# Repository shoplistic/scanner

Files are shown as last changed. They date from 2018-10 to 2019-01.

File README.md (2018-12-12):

# Barcode Scanner

### Links
[Headless Setup](https://desertbot.io/blog/headless-pi-zero-w-wifi-setup-windows)  
[Original Source](https://www.pyimagesearch.com/2018/05/21/an-opencv-barcode-and-qr-code-scanner-with-zbar/)

### TODO:
* [x] Install script
* [ ] Diagram / Schematic
* [x] pwm?

### RPi Pinout
|  pin  |  bcm  | usecase |
| :---: | :---: | :--- |
|  11 |  17 | RED LED |
|  12 |  18 | LIGHTNING PWM |
|  13 |  27 | GREEN LED |
|  15 |  22 | BLUE LED |
|  16 |  23 | SENSOR |

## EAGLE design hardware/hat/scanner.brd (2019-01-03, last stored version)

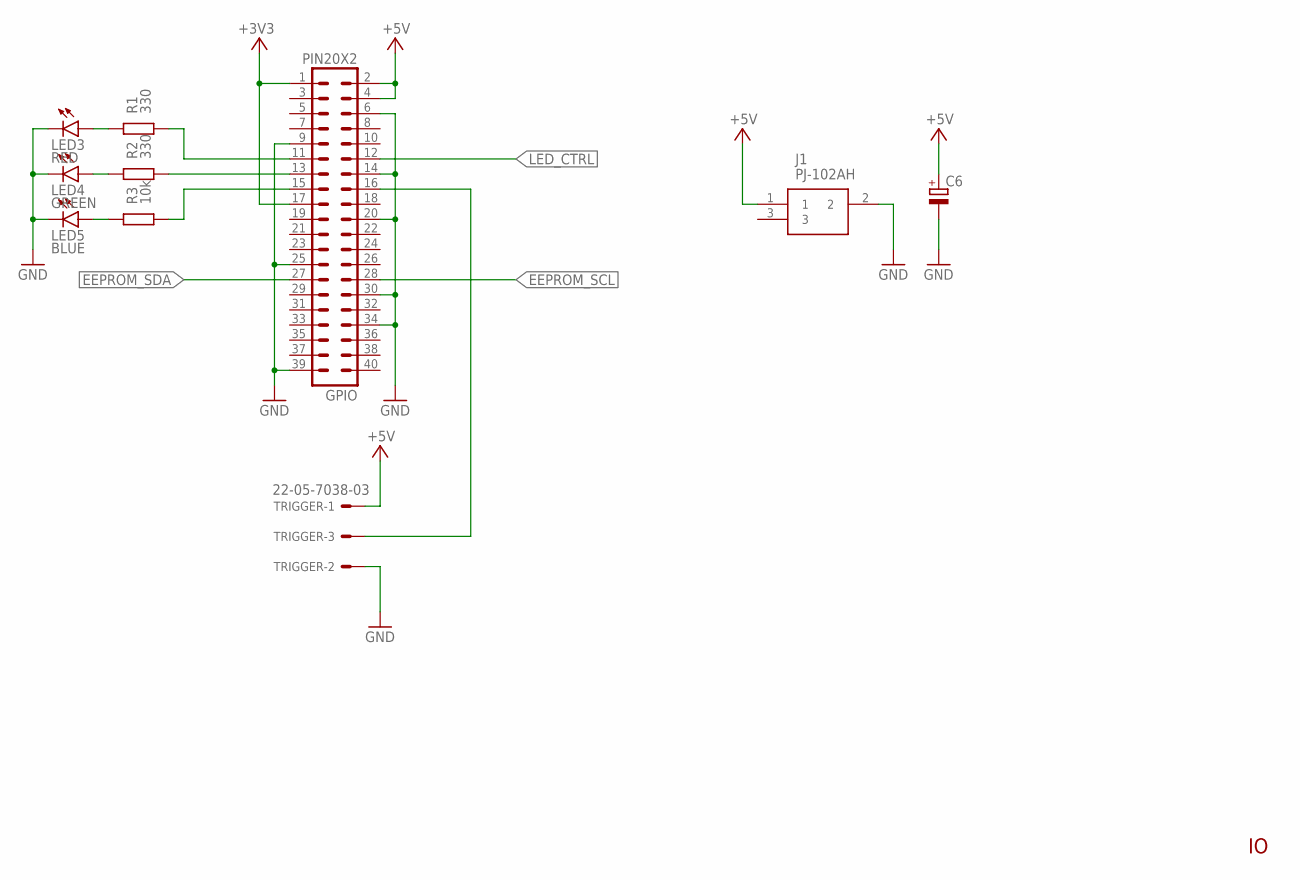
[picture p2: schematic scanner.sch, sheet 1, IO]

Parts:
C6: CPOL-EUCT6032; CT6032
GPIO: PIN20X2; PIN_20X2
J1: PJ-102AH
LED3: RED; CHIP-LED0805
LED4: GREEN; CHIP-LED0805
LED5: BLUE; CHIP-LED0805
R1, R2: 330; M0805; TOLERANCE 5%
R3: 10k; M0805; TOLERANCE 5%
TRIGGER: 22-05-7038-03; 7395-03

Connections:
+3V3: GPIO.1, GPIO.17; also elsewhere on the board
+5V: C6.+, GPIO.2, GPIO.4, J1.1, TRIGGER.1; also elsewhere on the board
EEPROM_SCL: GPIO.28; also elsewhere on the board
EEPROM_SDA: GPIO.27; also elsewhere on the board
GND: C6.-, GPIO.6, GPIO.9, GPIO.14, GPIO.20, GPIO.25, GPIO.30, GPIO.34, GPIO.39, J1.2, LED3.C, LED4.C, LED5.C, TRIGGER.2; also elsewhere on the board
LED3: GPIO.11, R1.1
LED4: GPIO.13, R2.1
LED5: GPIO.15, R3.1
LED_CTRL: GPIO.12; also elsewhere on the board
unnamed: LED3.A, R1.2
unnamed: LED4.A, R2.2
unnamed: LED5.A, R3.2
TRIGGER: GPIO.16, TRIGGER.3

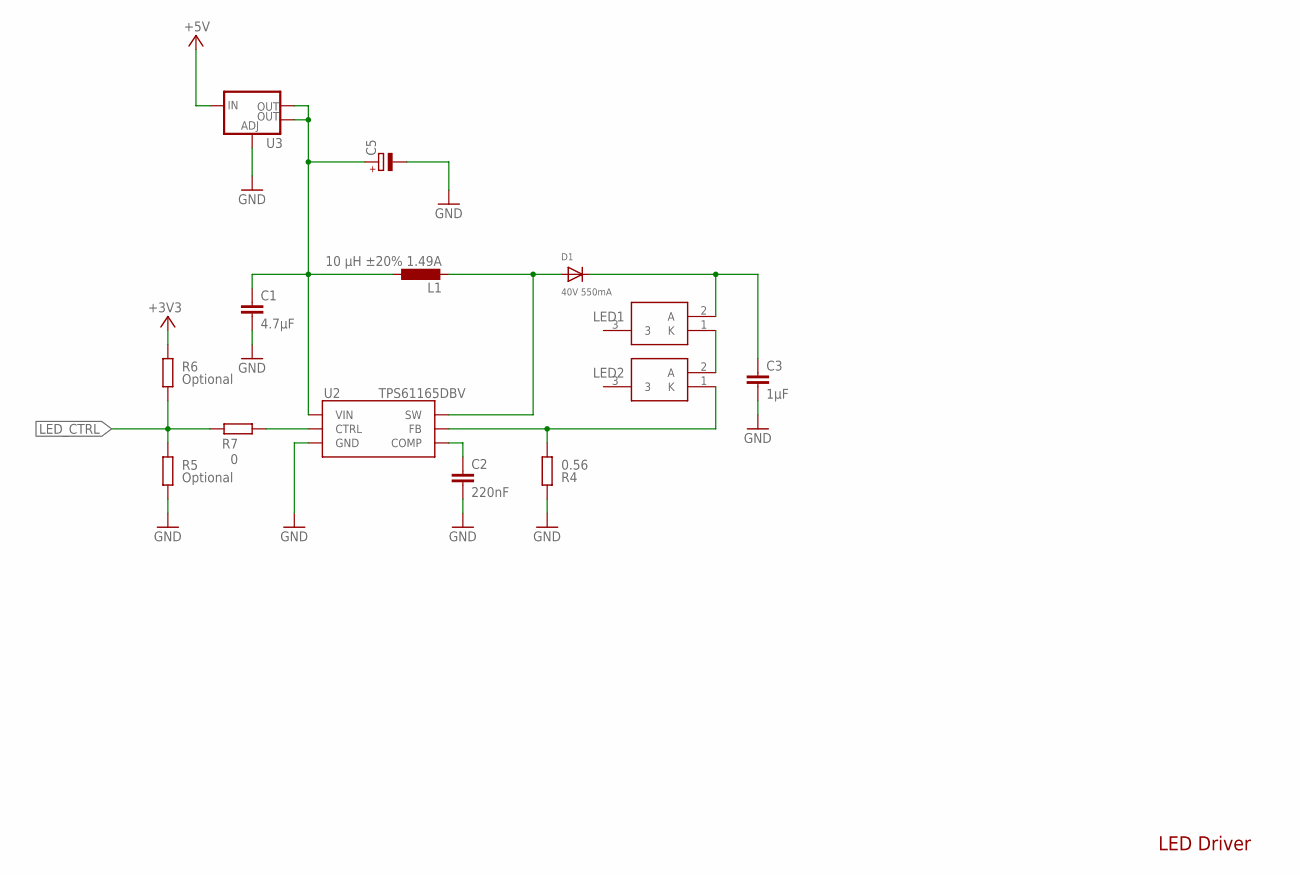
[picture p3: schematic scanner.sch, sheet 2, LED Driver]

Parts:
C1: 4.7μF; C0805K
C2: 220nF; C0805K
C3: 1μF; C0805K
C5: CPOL-EUCT6032; CT6032
D1: 40V 550mA; SOD-123
L1: 10 μH ±20% 1.49A; D53LC
LED1, LED2: LW_W5SM-JYKY-JKQL-1; LWW5SMJYKYJKQL1
R4: 0.56; M0805; TOLERANCE 5%
R5, R6: Optional; M0805; TOLERANCE 5%
R7: 0; M0805; TOLERANCE 5%
U2: TPS61165DBV; SOT-23-6
U3: V_REG_LM1117SOT223; SOT223

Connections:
+3V3: R6.2; also elsewhere on the board
+5V: U3.3 (IN); also elsewhere on the board
GND: C1.2, C2.2, C3.2, C5.-, R4.2, R5.1, U2.4 (GND), U3.1 (ADJ); also elsewhere on the board
LED_COMP: C2.1, U2.5 (COMP)
LED_CTRL: R5.2, R6.1, R7.2; also elsewhere on the board
LED_CTRL1: R7.1, U2.2 (CTRL)
LED_FB: LED2.1 (K), R4.1, U2.6 (FB)
LED_SW: D1.A, L1.2, U2.3 (SW)
unnamed: C3.1, D1.C, LED1.2 (A)
unnamed: LED1.1 (K), LED2.2 (A)
VCC: C1.1, C5.+, L1.1, U2.1 (VIN), U3.2 (OUT), U3.4 (OUT)

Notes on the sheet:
LED Driver

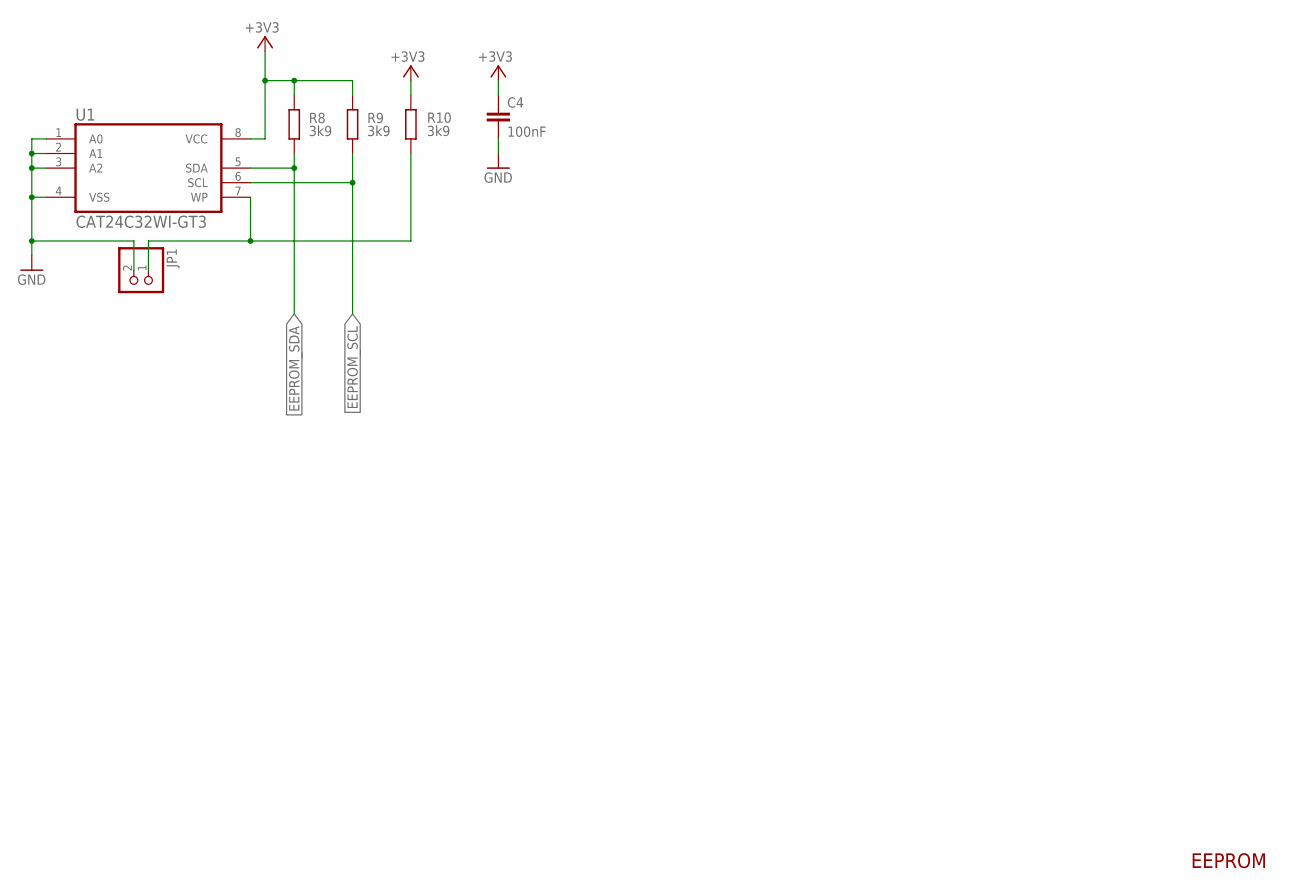
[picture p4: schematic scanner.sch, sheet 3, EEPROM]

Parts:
C4: 100nF; C0805K
JP1: PINHD-1X2; 1X02
R8, R9, R10: 3k9; M0805; TOLERANCE 5%
U1: CAT24C32WI-GT3; SOIC127P600X175-8N

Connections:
+3V3: C4.1, R8.2, R9.2, R10.1, U1.8 (VCC); also elsewhere on the board
EEPROM_SCL: R9.1, U1.6 (SCL); also elsewhere on the board
EEPROM_SDA: R8.1, U1.5 (SDA); also elsewhere on the board
EEPROM_WP: JP1.1, R10.2, U1.7 (WP)
GND: C4.2, JP1.2, U1.1 (A0), U1.2 (A1), U1.3 (A2), U1.4 (VSS); also elsewhere on the board

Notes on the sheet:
EEPROM

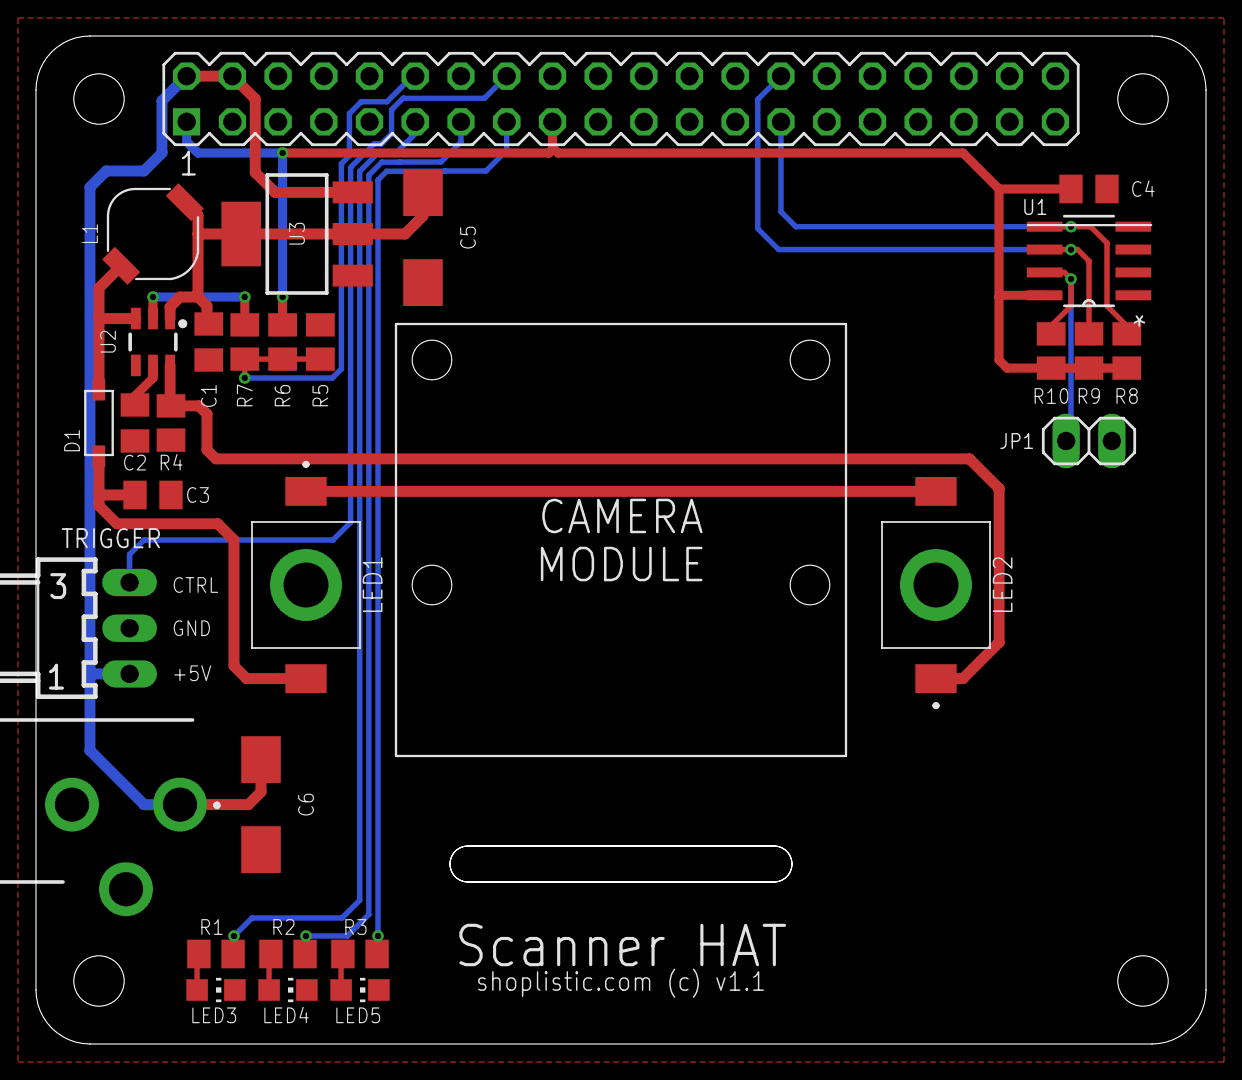
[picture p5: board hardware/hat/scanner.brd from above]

Board: 2 copper layers, 65.0 x 56.0 mm, 30 parts (0 on the bottom side), 21 nets.

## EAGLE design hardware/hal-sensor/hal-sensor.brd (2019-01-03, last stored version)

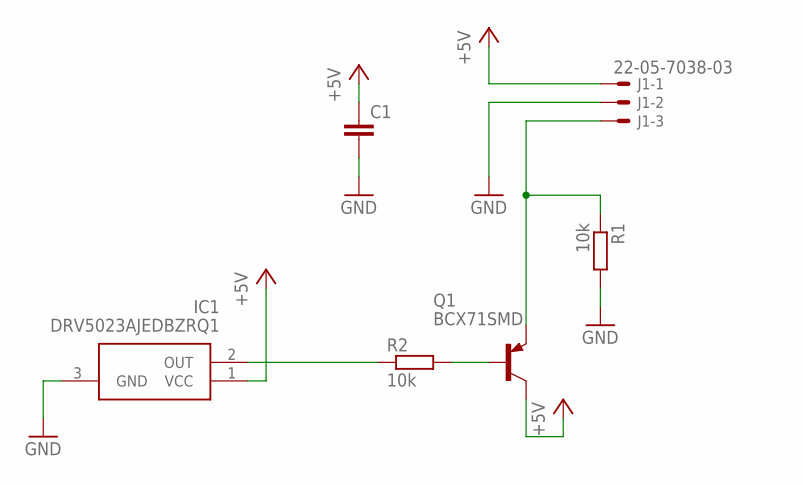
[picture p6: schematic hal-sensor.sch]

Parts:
C1: C-EUC0805; C0805
IC1: DRV5023AJEDBZRQ1; SOT95P237X112-3N
J1: 22-05-7038-03; 7395-03
Q1: BCX71SMD; SOT23
R1, R2: 10k; R0805

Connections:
+5V: C1.1, IC1.1 (VCC), J1.1, Q1.3 (C)
CTRL: J1.3, Q1.2 (E), R1.1
GND: C1.2, IC1.3 (GND), J1.2, R1.2
unnamed: IC1.2 (OUT), R2.1
unnamed: Q1.1 (B), R2.2

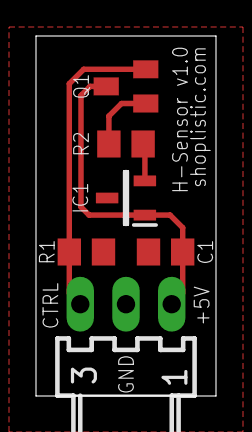
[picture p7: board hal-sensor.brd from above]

Board: 2 copper layers, 10.0 x 20.0 mm, 6 parts (0 on the bottom side), 5 nets.

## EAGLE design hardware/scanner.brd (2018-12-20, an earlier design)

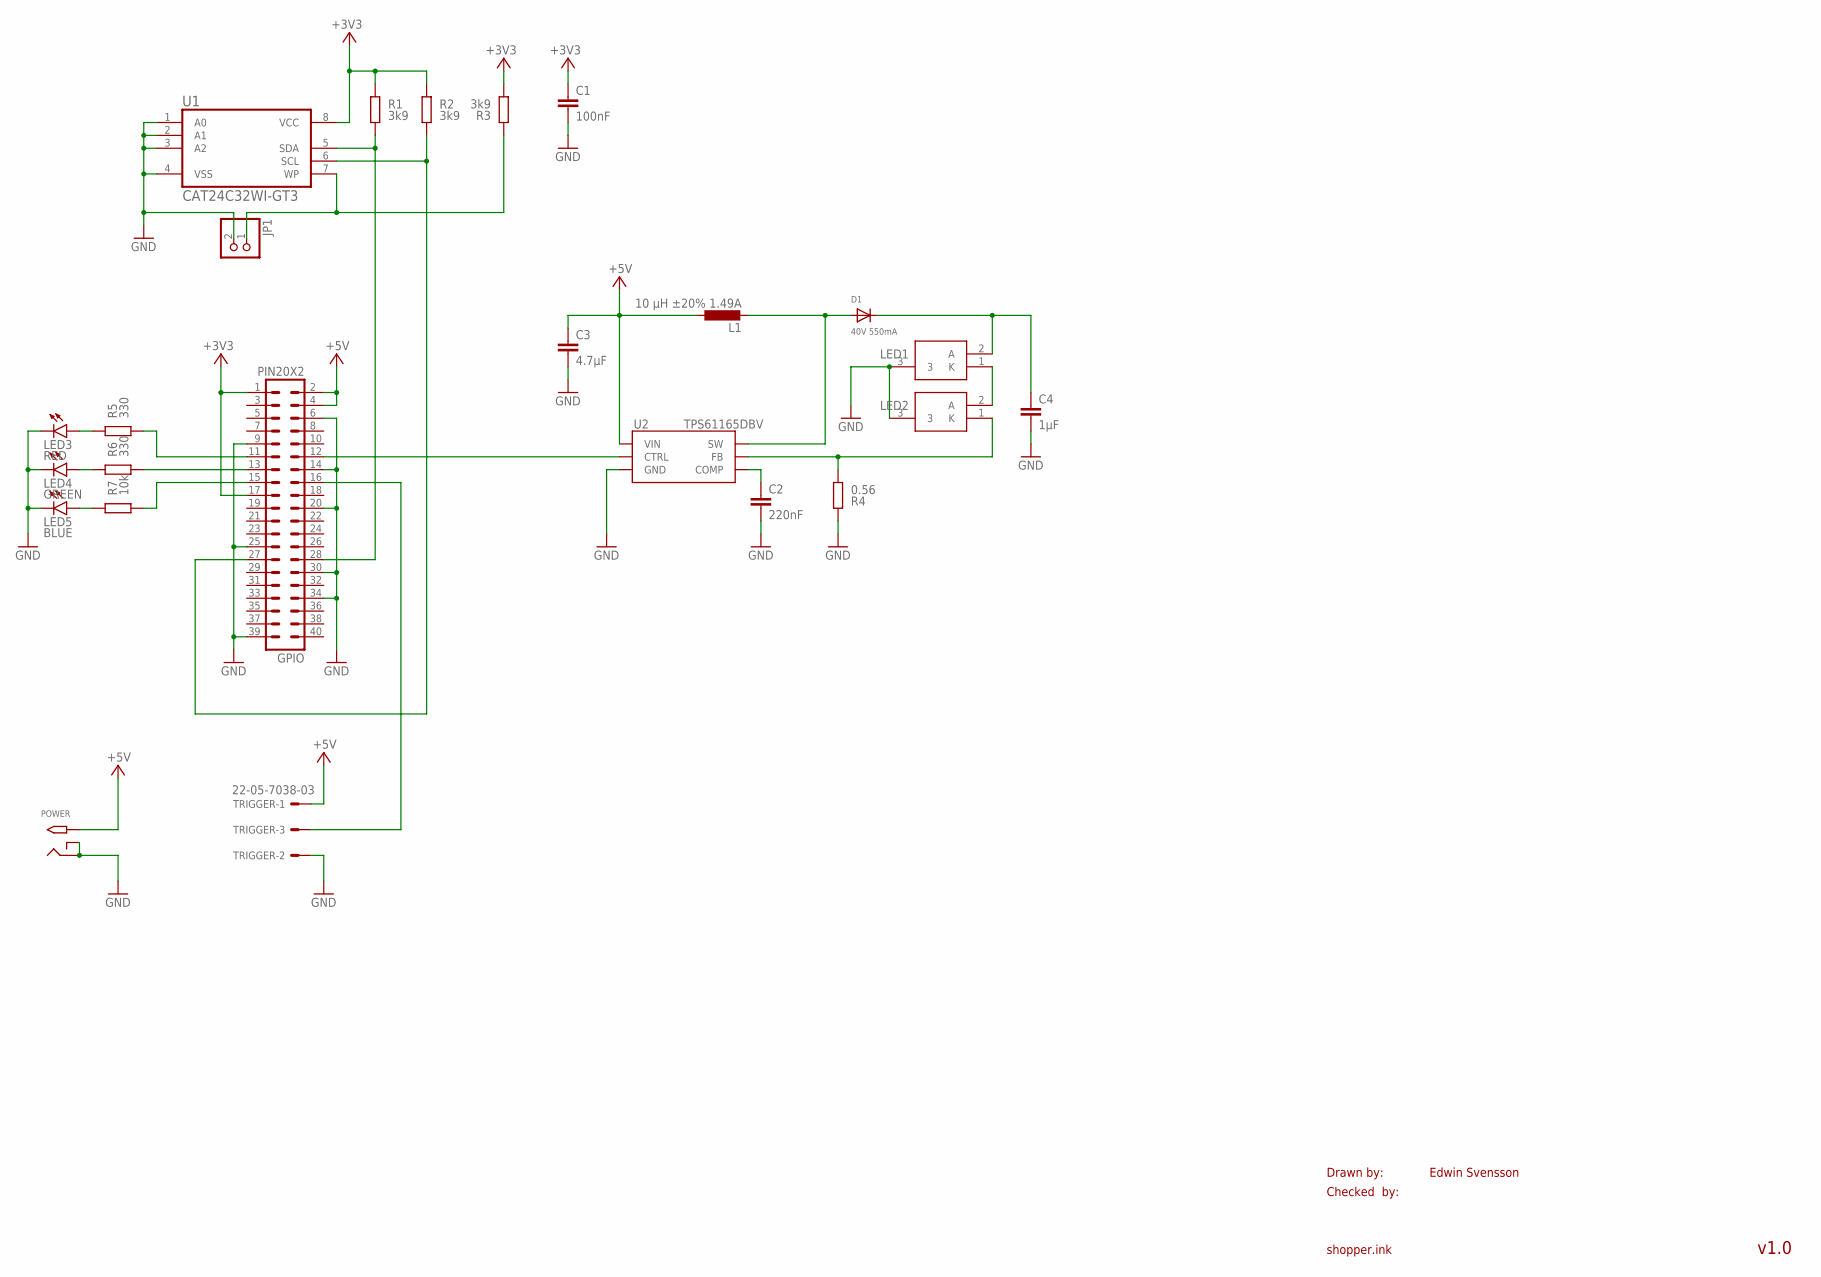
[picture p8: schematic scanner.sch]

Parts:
C1: 100nF; C0805K
C2: 220nF; C0805K
C3: 4.7μF; C0805K
C4: 1μF; C0805K
D1: 40V 550mA; SOD-123
GPIO: PIN20X2; PIN_20X2
JP1: PINHD-1X2; 1X02
L1: 10 μH ±20% 1.49A; D53LC
LED1, LED2: LW_W5SM-JYKY-JKQL-1; LWW5SMJYKYJKQL1
LED3: RED; CHIP-LED0805
LED4: GREEN; CHIP-LED0805
LED5: BLUE; CHIP-LED0805
POWER: 2.1MMJACKTHM; PJ-102A
R1, R2, R3: 3k9; M0805; TOLERANCE 5%
R4: 0.56; M0805; TOLERANCE 5%
R5, R6: 330; M0805; TOLERANCE 5%
R7: 10k; M0805; TOLERANCE 5%
TRIGGER: 22-05-7038-03; 7395-03
U1: CAT24C32WI-GT3; SOIC127P600X175-8N
U2: TPS61165DBV; SOT-23-6

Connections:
+3V3: C1.1, GPIO.1, GPIO.17, R1.2, R2.2, R3.1, U1.8 (VCC)
+5V: C3.1, GPIO.2, GPIO.4, L1.1, POWER.TIP, TRIGGER.1, U2.1 (VIN)
EEPROM_SCL: GPIO.27, R2.1, U1.6 (SCL)
EEPROM_SDA: GPIO.28, R1.1, U1.5 (SDA)
EEPROM_WP: JP1.1, R3.2, U1.7 (WP)
GND: C1.2, C2.2, C3.2, C4.2, GPIO.6, GPIO.9, GPIO.14, GPIO.20, GPIO.25, GPIO.30, GPIO.34, GPIO.39, JP1.2, LED1.3, LED2.3, LED3.C, LED4.C, LED5.C, POWER.RING, POWER.RING_SW, R4.2, TRIGGER.2, U1.1 (A0), U1.2 (A1), U1.3 (A2), U1.4 (VSS), U2.4 (GND)
LED3: GPIO.11, R5.1
LED4: GPIO.13, R6.1
LED5: GPIO.15, R7.1
LED_CTRL: GPIO.12, U2.2 (CTRL)
LED_FB: LED2.1 (K), R4.1, U2.6 (FB)
LED_SW: D1.A, L1.2, U2.3 (SW)
unnamed: C2.1, U2.5 (COMP)
unnamed: C4.1, D1.C, LED1.2 (A)
unnamed: LED1.1 (K), LED2.2 (A)
unnamed: LED3.A, R5.2
unnamed: LED4.A, R6.2
unnamed: LED5.A, R7.2
TRIGGER: GPIO.16, TRIGGER.3

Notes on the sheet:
Drawn by:
Checked by:
shopper.ink
Edwin Svensson
v1.0

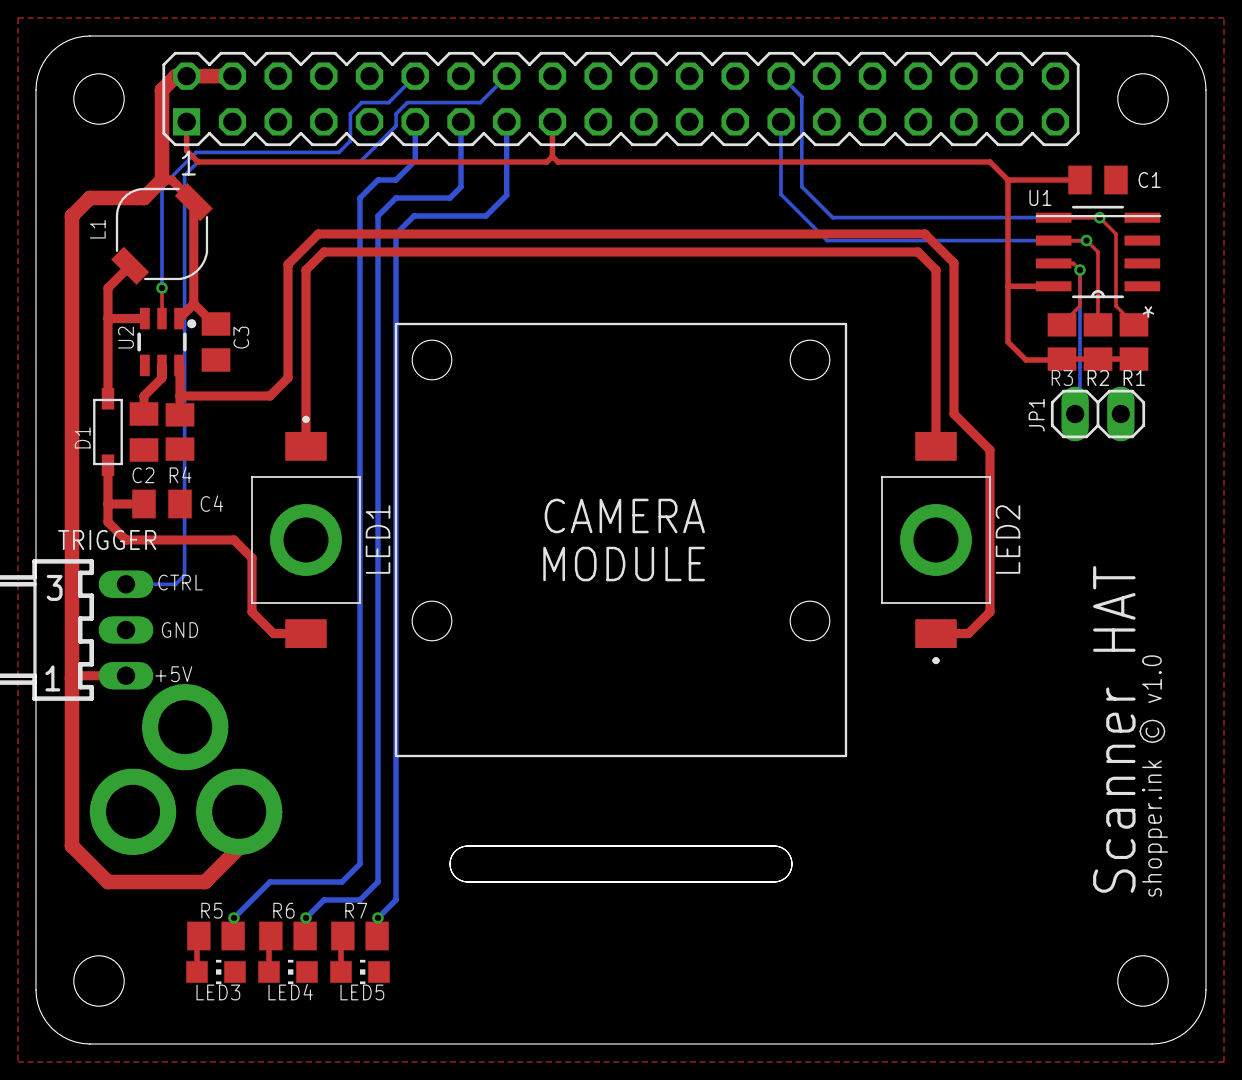
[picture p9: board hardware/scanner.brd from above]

Board: 2 copper layers, 65.0 x 56.0 mm, 24 parts (1 on the bottom side), 19 nets.

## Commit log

2018-10-28 i2c read / write
2018-11-20 add leds
2018-12-04 add hat files
    [scanner.brd, scanner.sch]
2018-12-04 update hat
    [scanner.brd, scanner.sch]
2018-12-04 move eagle libs
    [scanner.brd, scanner.sch]
2018-12-05 update pcb
    [scanner.brd, scanner.sch]
2018-12-06 added camera mounting holes
    [scanner.brd, scanner.sch]
2018-12-07 update bom
    [bom.ods]
2018-12-07 update board layout
    [scanner.brd]
2018-12-11 new power connector
    [scanner.brd, scanner.sch]
2018-12-11 rename routes
    [scanner.brd, scanner.sch]
2018-12-12 update text
    [scanner.brd]
2018-12-12 switch > sensor
2018-12-12 added proper sensor connector
    [scanner.brd, scanner.sch]
2018-12-15 update board
    [scanner.brd, scanner.sch]
2018-12-15 final layout?
    [scanner.brd, scanner.sch]
2018-12-15 address drc complaints, fixed font
    [scanner.brd, scanner.sch]
2018-12-19 redo eeprom area
    [scanner.brd]
2018-12-21 move to hat/
    [bom.ods, scanner.brd, scanner.sch]
2018-12-22 add HALL sensor board
    [hal-sensor.brd, hal-sensor.sch]
2018-12-22 make vias symetrical
    [hal-sensor.brd]
2018-12-22 move label
    [hal-sensor.brd]
2018-12-28 fixed issues with 1.0
    [scanner.brd, scanner.sch]
2018-12-28 change pin to 23
2018-12-28 add labels
    [scanner.brd]
2018-12-28 add 3V3 regulator
    [scanner.brd, scanner.sch]
2018-12-29 update url
    [scanner.brd]
2019-01-02 update layout
    [scanner.brd]
2019-01-02 tweak layout
    [scanner.brd]
2019-01-03 redo hall sensor board
    [hal-sensor.brd, hal-sensor.sch]
2019-01-03 tweak hal sensor board
    [hal-sensor.brd]
2019-01-03 remove gerber files
2019-08-08 move to hardware
    [bom.ods, hal-sensor.brd, hal-sensor.sch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]

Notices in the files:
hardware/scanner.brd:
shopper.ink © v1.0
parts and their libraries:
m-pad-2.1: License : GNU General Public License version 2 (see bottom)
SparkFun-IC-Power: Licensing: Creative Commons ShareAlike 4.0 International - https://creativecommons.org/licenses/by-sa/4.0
